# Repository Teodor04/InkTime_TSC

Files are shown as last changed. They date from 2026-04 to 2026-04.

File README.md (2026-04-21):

# InkTime Watch

A low-power e-paper smartwatch built around the **nRF52840**, designed for long battery life, sunlight readability, BLE connectivity, and essential wearable functionality such as notifications, timekeeping, basic motion tracking, and haptic feedback.

The platform integrates a **1.54" e-paper display**, **BLE 5.0**, **USB-C charging**, **battery fuel gauging**, **accelerometer-based activity tracking**, and a **haptic feedback driver**, all inside a compact custom enclosure.

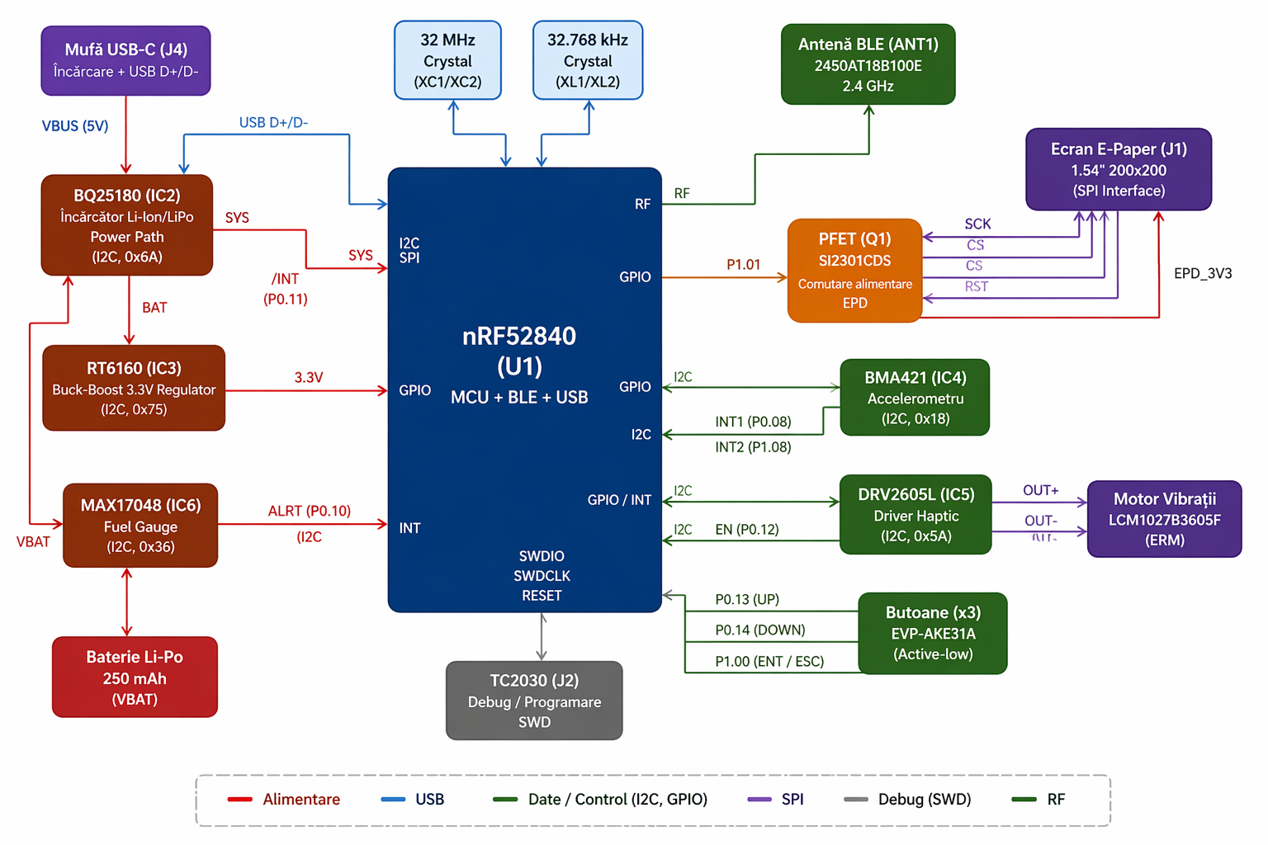
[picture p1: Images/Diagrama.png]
InkTime Watch Render


---

## Overview

InkTime Watch is a custom smartwatch hardware platform optimized for:
- **Ultra-low power consumption**
- **Always-readable e-paper display**
- **Bluetooth Low Energy communication**
- **Battery-powered operation**
- **Compact wearable form factor**

The system is centered on the **Nordic nRF52840**, which handles BLE communication, USB connectivity, GPIO control, and communication with all peripherals over SPI and I2C.

---

## Block Diagram

```text
                              ┌─────────────────────────────────────────────┐
                              │                 nRF52840                   │
                              │          MCU + BLE + USB Interface         │
                              │                                             │
                              │ SPI ───────────────► E-Paper Display        │
                              │ I2C ───────────────► BMA421                 │
                              │ I2C ───────────────► MAX17048               │
                              │ I2C ───────────────► BQ25180                │
                              │ I2C ───────────────► DRV2605L               │
                              │ GPIO ──────────────► Buttons                │
                              │ GPIO ──────────────► PFET Display Switch    │
                              │ SWDIO / SWDCLK ────► Tag-Connect SWD        │
                              │ D+ / D- ───────────► USB Type-C             │
                              │ ANT ───────────────► 2.4 GHz Antenna        │
                              │ XC1 / XC2 ─────────► 32 MHz Crystal         │
                              │ XL1 / XL2 ─────────► 32.768 kHz Crystal     │
                              └─────────────────────────────────────────────┘
                                              │
                                              ▼
                              ┌─────────────────────────────────────────────┐
                              │                 Power Tree                 │
                              │ USB 5V → BQ25180 → SYS → RT6160 → 3.3V    │
                              │ LiPo → BQ25180 BAT                         │
                              │ LiPo → MAX17048                            │
                              │ 3.3V → PFET → Switched EPD Rail           │
                              └─────────────────────────────────────────────┘

Bill of Materials (BOM)
Active & Critical Components
+----------------------+-------------------------------------------+-----------+------------+----------------------+
| Component            | Description                               | Package   | Part       | Datasheet            |
+----------------------+-------------------------------------------+-----------+------------+----------------------+
| nRF52840             | BLE 5.0 Cortex-M4F MCU                   | AQFN-73   | C190794    | Nordic nRF52840      |
| BQ25180YBGR          | 1A LiPo Charger (I2C)                    | DSBGA-8   | BQ25180YBGR| TI BQ25180           |
| MAX17048G+T10        | Fuel Gauge                              | TDFN-8    | C2682616   | Maxim MAX17048       |
| RT6160AWSC           | 3.3V Buck-Boost                         | WLCSP-15  | C7065276   | Richtek RT6160A      |
| BMA421               | IMU / Step Counter                      | LGA-12    | C5242966   | Bosch BMA421         |
| DRV2605YZFR          | Haptic Driver                           | DSBGA-9   | C527464    | TI DRV2605           |
| 2450AT18B100E        | 2.4GHz Antenna                          | 1206      | C2917717   | Johanson             |
| USBLC6-2SC6Y         | USB ESD Protection                      | SOT-23-6  | C2969755   | ST USBLC6-2          |
| KH-TYPE-C-16P        | USB-C Connector                         | SMD       | C168704    | Generic              |
| 503480-2400          | 24-pin FPC (EPD)                        | SMD       | —          | Molex                |
| DMG2305UX            | P-MOSFET (EPD power)                    | SOT-23    | C2940629   | Diodes Inc           |
| MBR0530              | Schottky Diode                          | SOD-123   | C77336     | Onsemi               |
| TC2030-IDC           | SWD Tag-Connect                         | PCB       | —          | Tag-Connect          |
+----------------------+-------------------------------------------+-----------+------------+----------------------+

Passive Components
+-----------------------------+-----------+--------+-----+-----------------------------+
| Component                   | Value     | Package| Qty | Function                    |
+-----------------------------+-----------+--------+-----+-----------------------------+
| Decoupling capacitors       | 100nF     | 0201   | 5   | MCU + peripherals           |
| Crystal load capacitors     | 12pF      | 0201   | 4   | Crystals                    |
| Bulk capacitors             | 4.7uF     | 0402   | 4   | Power buffering             |
| USB capacitor               | 4.7uF     | 0402   | 1   | USB stability               |
| Power capacitors            | 22uF      | 0402   | 2   | RT6160 input               |
| Charger capacitors          | 1uF       | 0402   | 3   | BQ25180 support            |
| E-paper capacitors          | 1uF / 50V | 0402   | 9   | Display driver             |
| MCU DC/DC inductor          | 10uH      | 0402   | 1   | nRF52840 regulator         |
| Buck-boost inductor         | 0.47uH    | 2012   | 1   | RT6160                     |
| I2C pull-up resistors       | 10k       | 0201   | 2   | SDA / SCL                  |
| USB-C CC resistors          | 5.1k      | 0201   | 2   | USB configuration          |
| Crystal                     | 32 MHz    | 2016   | 1   | MCU / RF clock             |
| Crystal                     | 32.768 kHz| 3215   | 1   | RTC                        |
+-----------------------------+-----------+--------+-----+-----------------------------+

## Hardware Description

### MCU - nRF52840

The **nRF52840** is the central processing unit of the InkTime watch. It integrates:

- **ARM Cortex-M4F** running at **64 MHz**, with floating-point unit
- **Bluetooth Low Energy 5.0**, used for time synchronization, notifications, and wireless communication
- **USB 2.0 Full Speed**, used for charging detection and firmware-related USB functionality
- **1 MB Flash** and **256 KB RAM**

The MCU coordinates all peripherals on the board. Communication with external devices is handled through:

- **SPI** for the e-paper display
- **I2C** for the motion sensor, fuel gauge, charger, regulator, and haptic driver

In addition to the communication buses, the MCU also manages:
- GPIO-based control lines for the display
- interrupt lines from peripherals
- button inputs
- haptic enable control
- SWD programming and debugging

---

### Power Architecture

The power system is designed around a rechargeable **single-cell Li-Po battery** and a **USB-C charging interface**.

```text
USB-C --> BQ25180 (charger / power path) --> Battery charging
                                     --> System rail

Battery --> MAX17048 --> battery monitoring
System rail / regulated rail --> MCU + peripherals
Display high-voltage rails --> generated by dedicated E-paper drive circuitry

BQ25180YBGR

The BQ25180 is the main charger and power-path management IC. It:

charges the Li-Po battery
monitors VBUS
provides system power management
generates interrupt/status events through PMIC_INT
communicates with the MCU over I2C
RT6160AWSC

The RT6160AWSC is used in the board power architecture as a switching regulator that helps generate the required regulated rail for the system.

MAX17048G+T10

The MAX17048 is a battery fuel gauge that monitors the battery voltage and estimates the state of charge (SOC) over I2C, allowing the firmware to display battery level and low-battery warnings.

E-Paper Display

The e-paper display is connected through an FPC connector and communicates with the MCU over SPI, together with several control GPIOs.

Signal	Direction	Description
SCK	MCU → EPD	SPI clock
MOSI	MCU → EPD	SPI data
EPD_CS	MCU → EPD	Chip select
EPD_DC	MCU → EPD	Data / Command select
EPD_RST	MCU → EPD	Hardware reset
EPD_BUSY	EPD → MCU	Busy flag

The display power rail is switched through a dedicated P-channel MOSFET, controlled by the MCU, so the panel can be powered only when needed. This reduces idle leakage and improves battery life.

The display driver circuitry generates the dedicated voltages required by the e-paper panel, such as:

PREVGH
PREVGL
VCOM
other gate/source driving rails required by the display
Motion Sensor - BMA421

The BMA421 is a low-power 3-axis accelerometer connected over I2C. It provides:

motion detection
step counting
orientation and activity-related sensing
interrupt-based wake-up functionality

Two interrupt lines are connected to the MCU:

IMU_INT1 for primary motion/step events
IMU_INT2 for additional event signaling or future extensions

This allows the MCU to remain in a low-power state and wake only when meaningful motion events occur.

Haptic Feedback - DRV2605 + ERM Motor

The DRV2605YZFR haptic driver controls the vibration motor used for user feedback. It connects to the MCU over I2C and also uses a dedicated digital enable signal:

HAPTIC_EN enables or disables the driver
OUT+ / OUT- drive the ERM motor
the chip supports waveform-based playback using its internal effects library

The haptic subsystem is used for:

notifications
alerts
button feedback
warning indications
USB Interface - KH-TYPE-C-16P + USBLC6-2SC6Y

The board uses a USB Type-C connector for charging and USB connectivity.

Main USB-related functions:

battery charging through VBUS
USB 2.0 D+ / D- lines connected to the nRF52840
ESD protection on USB data lines using USBLC6-2SC6Y
USB attach / power detection using the VBUS signal

The USB D+ / D- lines connect directly to the nRF52840 USB transceiver, while the USB-C configuration network ensures proper device operation.

RF Section - 2450AT18B100E Antenna

The board uses a 2.4 GHz chip antenna for BLE communication.

Key layout requirements for the RF section:

the antenna is placed at the PCB edge
copper is removed from the antenna keepout area
no signal traces are routed underneath the antenna
an impedance matching network is placed between the MCU RF pin and the antenna

This section is critical for BLE performance and must follow the recommended RF layout constraints.

SWD Debug - TC2030-IDC

Programming and debugging are performed through a Tag-Connect TC2030-IDC footprint.

The debug interface includes:

SWDIO
SWDCLK
nRESET
3.3V reference
GND

Additional exposed test pads are available for easier bring-up and debugging:

TP_SWDIO
TP_SWDCLK
TP_RESET
TP_3.3V
TP_GND

This allows programming and debugging without a permanently mounted header.

nRF52840 Pinout Specification
Shared I2C Bus

All I2C peripherals share the same bus, with pull-up resistors to 3.3V.

Pin	Function	Connected Devices
P0.06	SDA	BMA421, MAX17048, BQ25180, RT6160, DRV2605
P0.07	SCL	BMA421, MAX17048, BQ25180, RT6160, DRV2605
SPI Bus - E-Paper Display
Pin	Function	Description
P0.02	SCK	SPI clock for e-paper display
P0.03	MOSI	SPI data to e-paper display
P0.05	CS	E-paper chip select
P0.15	DC	Data / Command select
P0.16	RST	Display hardware reset
P0.17	BUSY	Display busy/status input
Display Power Control
Pin	Function	Description
P1.01	PFET Gate Control	Enables/disables the display power rail
Interrupts and Peripheral Control
Pin	Function	Description
P0.08	IMU_INT1	Primary motion / step wake interrupt
P1.08	IMU_INT2	Secondary motion interrupt
P0.10	ALRT	Fuel gauge alert / low battery interrupt
P0.11	PMIC_INT	Charger interrupt / status signal
P0.12	HAPTIC_EN	Enables the haptic driver
Physical Buttons

All buttons are connected as active-low inputs to GND.

Pin	Function
P0.13	Up Button
P0.14	Down Button
P1.00	Enter / Esc Button
Clocks and Debug
Pin / Signal	Function
XC1 / XC2	32 MHz crystal
XL1 / XL2	32.768 kHz crystal
SWDIO	SWD debug data
SWDCLK	SWD debug clock
nRESET	MCU reset
VBUS	USB power / attach detection
D+ / D-	Native USB 2.0
ANT	RF output to matching network and antenna
Pin Assignment Rationale

The pin assignment was chosen to keep routing compact and logically grouped:

I2C on P0.06 / P0.07 allows all low-speed peripherals to share a common bus.
SPI on P0.02 / P0.03 / P0.05 keeps display routing compact toward the FPC connector.
Display control pins are grouped close to the SPI bus to simplify routing.
Interrupt lines are placed on dedicated GPIOs so the MCU can identify wake sources immediately.
Buttons are assigned to GPIOs that can be routed toward the lower PCB edge, where the user interface is located.
HAPTIC_EN is placed near the I2C-related section for compact routing.
PFET gate control is placed on a dedicated GPIO to isolate display power switching from the communication buses.
SWDIO / SWDCLK / RESET are broken out to the Tag-Connect footprint for reliable programming and debug access.
Design Notes
The RF section must be kept clear of copper and routed carefully to preserve BLE performance.
The e-paper display requires dedicated high-voltage driving rails generated by the display power circuitry.
The charger, regulator, and battery monitoring ICs form the core of the power subsystem.
The design uses both communication buses and dedicated GPIO control to balance flexibility, low power, and routing simplicity.

License

This project is intended for educational use unless otherwise specified.

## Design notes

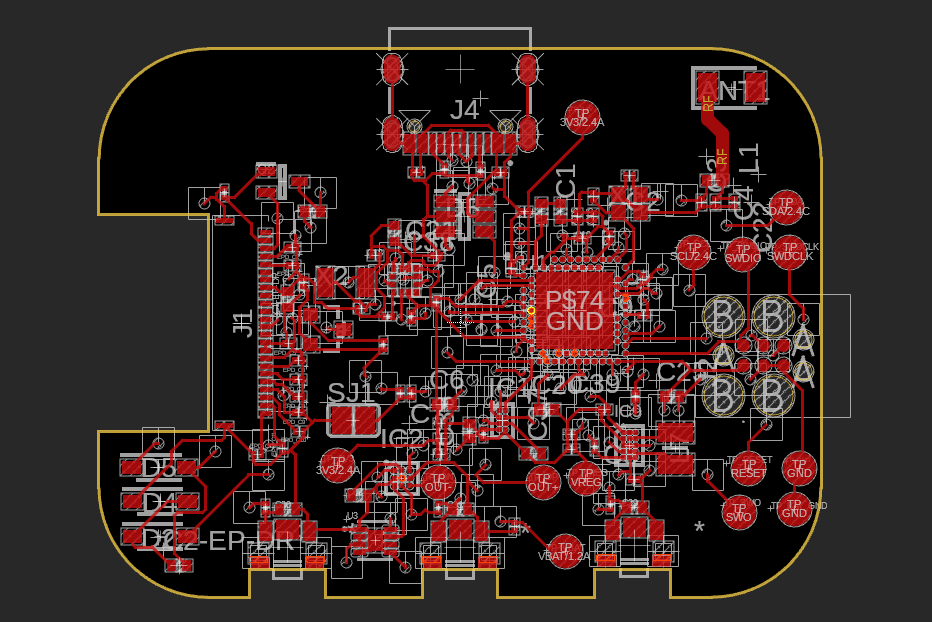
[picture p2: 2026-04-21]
Images/pcb2dtop.png

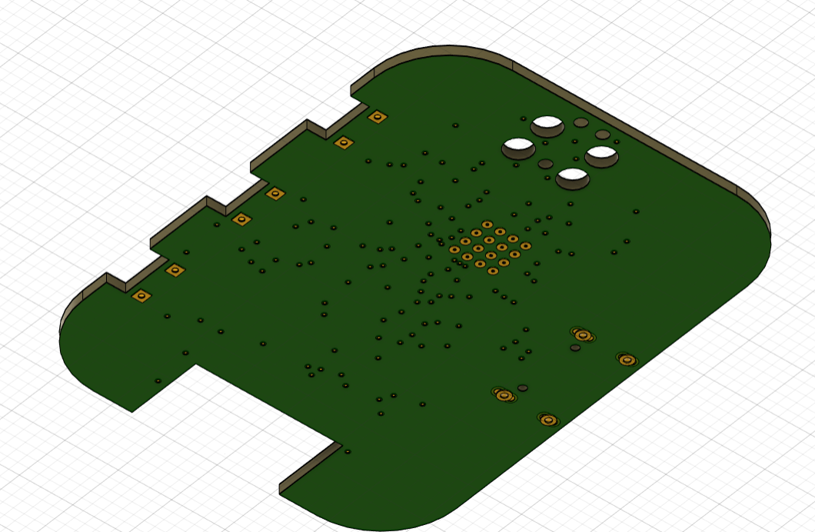
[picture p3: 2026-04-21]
Images/pcb 3d bottom.png

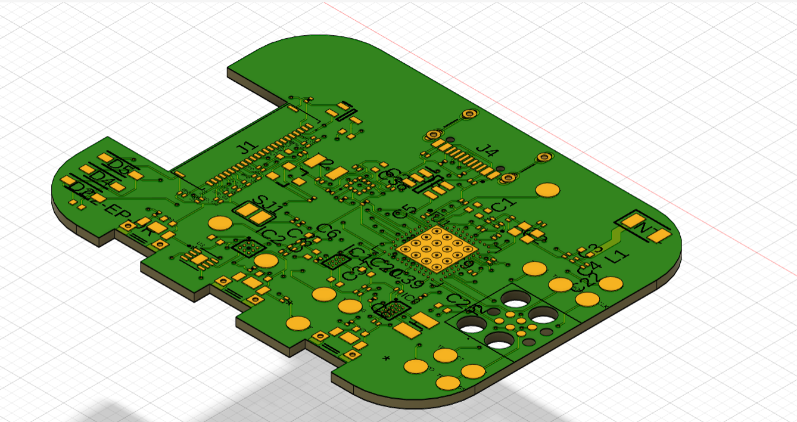
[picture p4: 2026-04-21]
Images/pcb 3d top.png

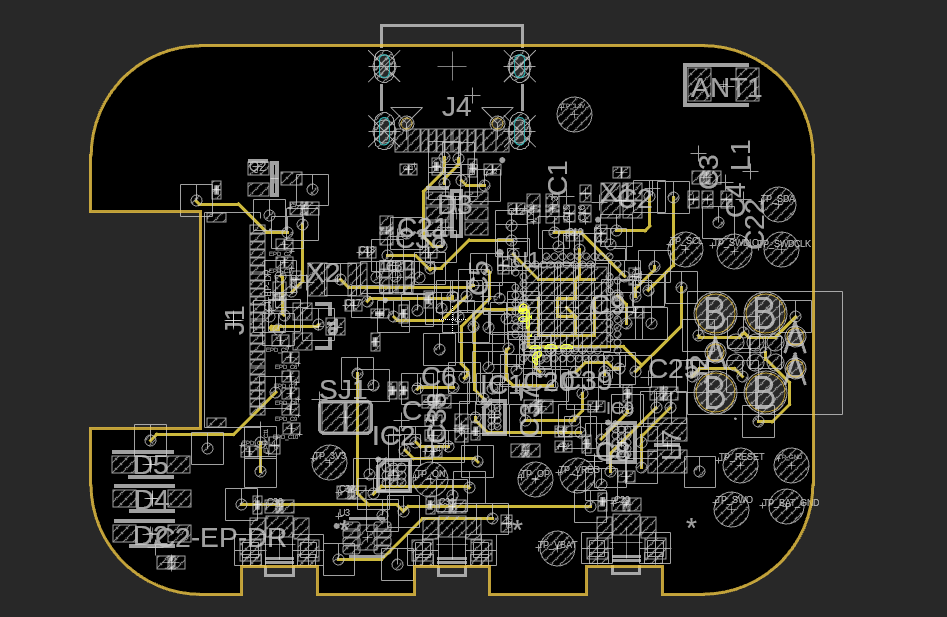
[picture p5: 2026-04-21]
Images/pcb2dgnd.png

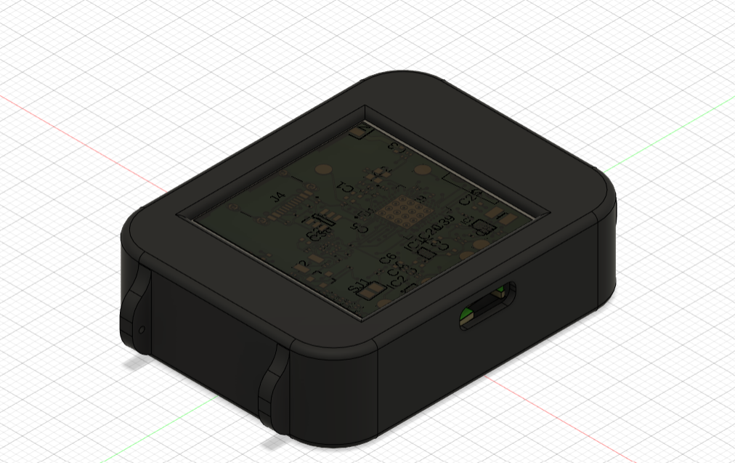
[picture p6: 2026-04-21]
Images/watch.png

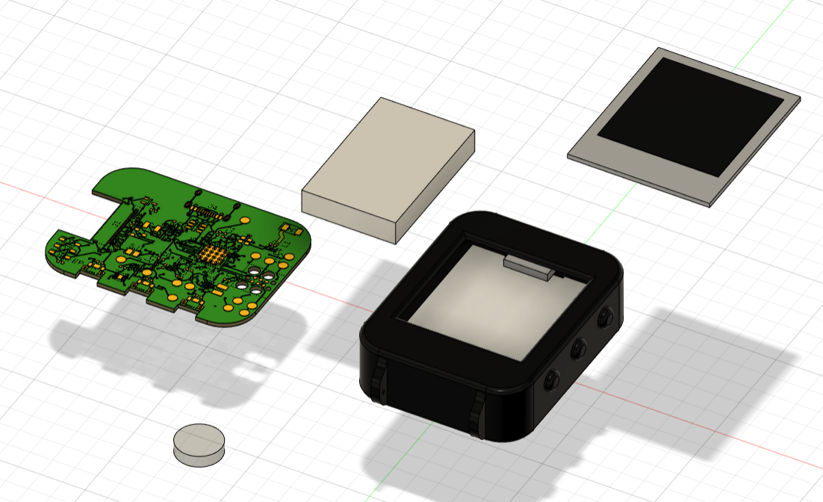
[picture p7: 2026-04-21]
Images/exploded.png

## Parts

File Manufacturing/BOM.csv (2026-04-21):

Part | Value | Device | Footprint Name | Detailed Description | ARROW_PART_NUMBER | ARROW_PRICE-STOCK | AVAILABILITY | CHECK_PRICES | COPYRIGHT | DESCRIPTION | DIGI-KEY_PART_NUMBER_1 | DIGI-KEY_PART_NUMBER_2 | DIGI-KEY_PART_NUMBER_3 | HEIGHT | JLCPCB | MANUFACTURER_NAME | MANUFACTURER_PART_NUMBER | MF | MOUSER_PART_NUMBER | MOUSER_PRICE-STOCK | MP | PACKAGE | POPULARITY | PRICE | PROD_ID | PURCHASE-URL | SNAPEDA_LINK | TP_SIGNAL_NAME | VALUE
ANT1 | 2450AT18B100E_2450AT18B100E | 2450AT18B100E_2450AT18B100E | 2450AT18B100E_ANTC3216X140N | Antennas 2.45GHz ANTENNA | 2450AT18B100E | https://www.arrow.com/en/products/2450at18b100e/johanson-dielectrics?utm_currency=USD&region=nac |  |  |  | Antennas 2.45GHz ANTENNA |  |  |  | 1.4mm |  | JOHANSON TECHNOLOGY | 2450AT18B100E |  | 609-2450AT18B100E | https://www.mouser.co.uk/ProductDetail/Johanson-Technology/2450AT18B100E?qs=yCnrNFeXz%252Bh5MFsFIXGZGA%3D%3D
C1 | 12pF | NORDIC_NRF_3_CAPACITOR_0201_L | NORDIC_NRF_3_RESC0201_L | Generic chip capacitor
C1-EP-DR | 10uF | NORDIC_NRF_3_CAPACITOR_0402_L | NORDIC_NRF_3_RESC0402_L | Generic chip capacitor
C2 | 12pF | NORDIC_NRF_3_CAPACITOR_0201_L | NORDIC_NRF_3_RESC0201_L | Generic chip capacitor
C2-EP-DR | 4.7uF/25V | NORDIC_NRF_3_CAPACITOR_0402_L | NORDIC_NRF_3_RESC0402_L | Generic chip capacitor
C3 | 1pF | NORDIC_NRF_3_CAPACITOR_0201_L | NORDIC_NRF_3_RESC0201_L | Generic chip capacitor
C4 | 1pF | NORDIC_NRF_3_CAPACITOR_0201_L | NORDIC_NRF_3_RESC0201_L | Generic chip capacitor
C5 | 100nF | NORDIC_NRF_3_CAPACITOR_0201_L | NORDIC_NRF_3_RESC0201_L | Generic chip capacitor
C6 | 4.7µF | NORDIC_NRF_3_CAPACITOR_0402_L | NORDIC_NRF_3_RESC0402_L | Generic chip capacitor
C7 | 100nF | NORDIC_NRF_3_CAPACITOR_0201_L | NORDIC_NRF_3_RESC0201_L | Generic chip capacitor
C8 | 100nF | NORDIC_NRF_3_CAPACITOR_0201_L | NORDIC_NRF_3_RESC0201_L | Generic chip capacitor
C9 | 820pF | NORDIC_NRF_3_CAPACITOR_0201_L | NORDIC_NRF_3_RESC0201_L | Generic chip capacitor
C10 | N.C. | NORDIC_NRF_3_CAPACITOR_0201_L | NORDIC_NRF_3_RESC0201_L | Generic chip capacitor
C11 | 100pF | NORDIC_NRF_3_CAPACITOR_0201_L | NORDIC_NRF_3_RESC0201_L | Generic chip capacitor
C12 | 100nF | NORDIC_NRF_3_CAPACITOR_0201_L | NORDIC_NRF_3_RESC0201_L | Generic chip capacitor
C13 | N.C. | NORDIC_NRF_3_CAPACITOR_0201_L | NORDIC_NRF_3_RESC0201_L | Generic chip capacitor
C14 | 4.7µF | NORDIC_NRF_3_CAPACITOR_0201_L | NORDIC_NRF_3_RESC0201_L | Generic chip capacitor
C15 | 1.0µF | NORDIC_NRF_3_CAPACITOR_0201_L | NORDIC_NRF_3_RESC0201_L | Generic chip capacitor
C16 | 47nF | NORDIC_NRF_3_CAPACITOR_0201_L | NORDIC_NRF_3_RESC0201_L | Generic chip capacitor
C17 | 12pF | NORDIC_NRF_3_CAPACITOR_0201_L | NORDIC_NRF_3_RESC0201_L | Generic chip capacitor
C18 | 12pF | NORDIC_NRF_3_CAPACITOR_0201_L | NORDIC_NRF_3_RESC0201_L | Generic chip capacitor
C19 | 100nF | NORDIC_NRF_3_CAPACITOR_0201_L | NORDIC_NRF_3_RESC0201_L | Generic chip capacitor
C20 | 4.7µF | NORDIC_NRF_3_CAPACITOR_0402_L | NORDIC_NRF_3_RESC0402_L | Generic chip capacitor
C21 | 4.7µF | NORDIC_NRF_3_CAPACITOR_0201_L | NORDIC_NRF_3_RESC0201_L | Generic chip capacitor
C22 | N.C. | NORDIC_NRF_3_CAPACITOR_0201_L | NORDIC_NRF_3_RESC0201_L | Generic chip capacitor
C23 | 0.1uF | NORDIC_NRF_3_CAPACITOR_0201_L | NORDIC_NRF_3_RESC0201_L | Generic chip capacitor
C24 | 10uF | NORDIC_NRF_3_CAPACITOR_0201_L | NORDIC_NRF_3_RESC0201_L | Generic chip capacitor
C25 | 22uF | NORDIC_NRF_3_CAPACITOR_0402_L | NORDIC_NRF_3_RESC0402_L | Generic chip capacitor
C27 | 0.1uF | NORDIC_NRF_3_CAPACITOR_0201_L | NORDIC_NRF_3_RESC0201_L | Generic chip capacitor
C29 | 1uF | NORDIC_NRF_3_CAPACITOR_0402_L | NORDIC_NRF_3_RESC0402_L | Generic chip capacitor
C30 | 1uF | NORDIC_NRF_3_CAPACITOR_0402_L | NORDIC_NRF_3_RESC0402_L | Generic chip capacitor
C31 | 1uF | NORDIC_NRF_3_CAPACITOR_0402_L | NORDIC_NRF_3_RESC0402_L | Generic chip capacitor
C32 | 1uF | NORDIC_NRF_3_CAPACITOR_0402_L | NORDIC_NRF_3_RESC0402_L | Generic chip capacitor
C33 | 22uF | NORDIC_NRF_3_CAPACITOR_0402_L | NORDIC_NRF_3_RESC0402_L | Generic chip capacitor
C34 | 0.1uF | NORDIC_NRF_3_CAPACITOR_0201_L | NORDIC_NRF_3_RESC0201_L | Generic chip capacitor
C37 | 1uF | NORDIC_NRF_3_CAPACITOR_0402_L | NORDIC_NRF_3_RESC0402_L | Generic chip capacitor
C38 | 1uF | NORDIC_NRF_3_CAPACITOR_0402_L | NORDIC_NRF_3_RESC0402_L | Generic chip capacitor
C39 | 10uF | NORDIC_NRF_3_CAPACITOR_0201_L | NORDIC_NRF_3_RESC0201_L | Generic chip capacitor
C42 | 0.1uF | NORDIC_NRF_3_CAPACITOR_0201_L | NORDIC_NRF_3_RESC0201_L | Generic chip capacitor
C43 | 4.7uF | NORDIC_NRF_3_CAPACITOR_0201_L | NORDIC_NRF_3_RESC0201_L | Generic chip capacitor
D2 | ESP32_C6_LIBRARY_5_MBR0530 | ESP32_C6_LIBRARY_5_MBR0530 | ESP32_C6_LIBRARY_5_SOD3716X135N | ON SEMICONDUCTOR - MBR0530 - DIODE, SCHOTTKY, 0.5A, 30V, SOD-123 |  |  | In Stock | https://www.snapeda.com/parts/MBR0530/Onsemi/view-part/?ref=eda |  | Diode Schottky 30 V 500mA Surface Mount SOD-123 |  |  |  |  |  |  |  | ON Semiconductor |  |  | MBR0530 | SOD-123-2 ON Semiconductor |  | None |  | https://www.snapeda.com/api/url_track_click_mouser/?unipart_id=179458&manufacturer=ON Semiconductor&part_name=MBR0530&search_term=None | https://www.snapeda.com/parts/MBR0530/Onsemi/view-part/?ref=snap
D3 | ESP32_C6_LIBRARY_3_USBLC6-2SC6Y | ESP32_C6_LIBRARY_3_USBLC6-2SC6Y | ESP32_C6_LIBRARY_3_SOT95P280X145-6N | Low Cap. ESD Protection Auto SOT-23-6 STMicroelectronics USBLC6-2SC6Y, Dual Uni-Directional TVS Diode Array, 6-Pin SOT-23 |  |  | In Stock | https://www.snapeda.com/parts/USBLC6-2SC6Y/STMicroelectronics/view-part/?ref=eda |  | 17V Clamp 5A (8/20µs) Ipp Tvs Diode Surface Mount SOT-23-6 |  |  |  |  |  |  |  | STMicroelectronics |  |  | USBLC6-2SC6Y | SOT-23-6 STMicroelectronics |  | None |  |  | https://www.snapeda.com/parts/USBLC6-2SC6Y/STMicroelectronics/view-part/?ref=snap
D4 | ESP32_C6_LIBRARY_5_MBR0530 | ESP32_C6_LIBRARY_5_MBR0530 | ESP32_C6_LIBRARY_5_SOD3716X135N | ON SEMICONDUCTOR - MBR0530 - DIODE, SCHOTTKY, 0.5A, 30V, SOD-123 |  |  | In Stock | https://www.snapeda.com/parts/MBR0530/Onsemi/view-part/?ref=eda |  | Diode Schottky 30 V 500mA Surface Mount SOD-123 |  |  |  |  |  |  |  | ON Semiconductor |  |  | MBR0530 | SOD-123-2 ON Semiconductor |  | None |  | https://www.snapeda.com/api/url_track_click_mouser/?unipart_id=179458&manufacturer=ON Semiconductor&part_name=MBR0530&search_term=None | https://www.snapeda.com/parts/MBR0530/Onsemi/view-part/?ref=snap
D5 | ESP32_C6_LIBRARY_5_MBR0530 | ESP32_C6_LIBRARY_5_MBR0530 | ESP32_C6_LIBRARY_5_SOD3716X135N | ON SEMICONDUCTOR - MBR0530 - DIODE, SCHOTTKY, 0.5A, 30V, SOD-123 |  |  | In Stock | https://www.snapeda.com/parts/MBR0530/Onsemi/view-part/?ref=eda |  | Diode Schottky 30 V 500mA Surface Mount SOD-123 |  |  |  |  |  |  |  | ON Semiconductor |  |  | MBR0530 | SOD-123-2 ON Semiconductor |  | None |  | https://www.snapeda.com/api/url_track_click_mouser/?unipart_id=179458&manufacturer=ON Semiconductor&part_name=MBR0530&search_term=None | https://www.snapeda.com/parts/MBR0530/Onsemi/view-part/?ref=snap
EPD_C1 | 1uF/50V | NORDIC_NRF_3_CAPACITOR_0201_L | NORDIC_NRF_3_RESC0201_L | Generic chip capacitor
EPD_C2 | 1uF/50V | NORDIC_NRF_3_CAPACITOR_0201_L | NORDIC_NRF_3_RESC0201_L | Generic chip capacitor
EPD_C5 | 0.1uF/50V | NORDIC_NRF_3_CAPACITOR_0201_L | NORDIC_NRF_3_RESC0201_L | Generic chip capacitor
EPD_C6 | 1uF/50V | NORDIC_NRF_3_CAPACITOR_0201_L | NORDIC_NRF_3_RESC0201_L | Generic chip capacitor
EPD_C7 | 1uF/50V | NORDIC_NRF_3_CAPACITOR_0201_L | NORDIC_NRF_3_RESC0201_L | Generic chip capacitor
EPD_C8 | 1uF/50V | NORDIC_NRF_3_CAPACITOR_0201_L | NORDIC_NRF_3_RESC0201_L | Generic chip capacitor
EPD_C9 | 1uF/50V | NORDIC_NRF_3_CAPACITOR_0201_L | NORDIC_NRF_3_RESC0201_L | Generic chip capacitor
EPD_C10 | 1uF/50V | NORDIC_NRF_3_CAPACITOR_0201_L | NORDIC_NRF_3_RESC0201_L | Generic chip capacitor
EPD_C11 | 1uF/50V | NORDIC_NRF_3_CAPACITOR_0201_L | NORDIC_NRF_3_RESC0201_L | Generic chip capacitor
EPD_C12 | 1uF/50V | NORDIC_NRF_3_CAPACITOR_0201_L | NORDIC_NRF_3_RESC0201_L | Generic chip capacitor
IC1 | BQ25180YBGR_BQ25180YBGR | BQ25180YBGR_BQ25180YBGR | BQ25180YBGR_BGA8C40P2X4_100X155X50 | Charger IC Lithium Ion/Polymer, Lithium Iron Phosphate 8-DSBGA (1.6x1.1) | BQ25180YBGR | https://www.arrow.com/en/products/bq25180ybgr/texas-instruments?utm_currency=USD&region=nac |  |  |  | Charger IC Lithium Ion/Polymer, Lithium Iron Phosphate 8-DSBGA (1.6x1.1) |  |  |  | 0.5mm |  | Texas Instruments | BQ25180YBGR |  | 595-BQ25180YBGR | https://www.mouser.co.uk/ProductDetail/Texas-Instruments/BQ25180YBGR?qs=doiCPypUmgEWjAK%252BJAX6Tw%3D%3D
IC2 | DRV2605YZFR_DRV2605YZFR | DRV2605YZFR_DRV2605YZFR | DRV2605YZFR_BGA9C50P3X3_144X144X62 | Haptic Driver for ERM/LRA with Built-In Library and Smart Loop Architecture | DRV2605YZFR | https://www.arrow.com/en/products/drv2605yzfr/texas-instruments?region=nac |  |  |  | Haptic Driver for ERM/LRA with Built-In Library and Smart Loop Architecture |  |  |  | 0.625mm |  | Texas Instruments | DRV2605YZFR
IC3 | BMA423_BMA423 | BMA423_BMA423 | BMA423_BMA423 | Accelerometers Triaxial low-g 12bit Acceleration Sensor | BMA423 | https://www.arrow.com/en/products/bma423/bosch |  |  |  | Accelerometers Triaxial low-g 12bit Acceleration Sensor |  |  |  | 1mm |  | BOSCH | BMA423 |  | 262-BMA423 | https://www.mouser.co.uk/ProductDetail/Bosch-Sensortec/BMA423?qs=HXFqYaX1Q2xC%252BSgeGoX3mg%3D%3D
IC9 | RT6160AWSC_RT6160AWSC | RT6160AWSC_RT6160AWSC | RT6160AWSC_BGA15C40P3X5_140X230X60 | Buck-Boost Regulator Positive Output Step-Up/Step-Down I2C DC-DC Controller IC 15-WL-CSP (BSC) (1.4x2.3) |  |  |  |  |  | Buck-Boost Regulator Positive Output Step-Up/Step-Down I2C DC-DC Controller IC 15-WL-CSP (BSC) (1.4x2.3) |  |  |  | 0.6mm |  | RICHTEK | RT6160AWSC |  | 835-RT6160AWSC | https://www.mouser.co.uk/ProductDetail/Richtek/RT6160AWSC?qs=amGC7iS6iy%2FLd9PSoixZXQ%3D%3D
J1 | 503480-2400_503480-2400 | 503480-2400_503480-2400 | 503480-2400_5034802400 | FFC & FPC Connectors 0.5mm FPC RA SMT Dual Contact 24Ckt |  |  |  |  |  | FFC & FPC Connectors 0.5mm FPC RA SMT Dual Contact 24Ckt |  |  |  | 1.87mm |  | Molex | 503480-2400 |  | 538-503480-2400 | https://www.mouser.co.uk/ProductDetail/Molex/503480-2400?qs=OAhjpuo3Vu7efIoxFh9AOw%3D%3D
J2 | TC2030-IDC_TC2030-IDC | TC2030-IDC_TC2030-IDC | TC2030-IDC_TC2030IDC | CABLE ADAPTER 6 POS |  |  |  |  |  | CABLE ADAPTER 6 POS |  |  |  | 19mm |  | Tag Connect | TC2030-IDC
J4 | KH-TYPE-C-16P_KH-TYPE-C-16P | KH-TYPE-C-16P_KH-TYPE-C-16P | KH-TYPE-C-16P_KINGHELM_KH-TYPE-C-16P | Check availability |  |  | Not in stock | https://www.snapeda.com/parts/KH-TYPE-C-16P/Kinghelm/view-part/?ref=eda |  |  |  |  |  |  |  |  |  | kinghelm |  |  | KH-TYPE-C-16P | None |  | None |  |  | https://www.snapeda.com/parts/KH-TYPE-C-16P/Kinghelm/view-part/?ref=snap
L1 | 3.9nH | NORDIC_NRF_2_INDUCTOR_0402_L | NORDIC_NRF_2_RESC0402_L | Generic chip inductor
L2 | 10µH | NORDIC_NRF_2_INDUCTOR_0402_L | NORDIC_NRF_2_RESC0402_L | Generic chip inductor
L3 | 15nH | NORDIC_NRF_2_INDUCTOR_0402_L | NORDIC_NRF_2_RESC0402_L | Generic chip inductor
L5 | 68uH | NORDIC_NRF_2_INDUCTOR_0402_L | NORDIC_NRF_2_RESC0402_L | Generic chip inductor
L7 | MLP2016SR47MT0S1_FTC252012SR47MBCA | MLP2016SR47MT0S1_FTC252012SR47MBCA | MLP2016SR47MT0S1_INDC2016X100N | SMD / SMT Inductors (Coils), L=0.47?H, L x W x T : |  |  |  |  |  | SMD / SMT Inductors (Coils), L=0.47?H, L x W x T : |  |  |  | 1mm | https://jlcpcb.com/partdetail/6763488-FTC252012SR47MBCA/C5832368 | TDK | FTC252012SR47MBCA
Q1 | 20V/4.2A/52mO/1.4W | ESP32_C6_LIBRARY_4_ESP32_WROVER_SPARKFUN-DISCRETESEMI_MOSFET_PCH-DMG2305UX-7 | ESP32_C6_LIBRARY_4_ESP32_C6_LIBRARY_4_ESP32_C6_LIBRARY_4_ESP32_C6_LIBRARY_4_ESP32_WROVER_SPARKFUN-DISCRETESEMI_SOT23-3 | P-channel MOSFETs |  |  |  |  |  |  |  |  |  |  |  |  |  |  |  |  |  |  |  |  | TRAN-14388 |  |  |  | 20V/4.2A/52mO/1.4W
Q2 | ESP32_C6_LIBRARY_6_SI1308EDL-T1-GE3 | ESP32_C6_LIBRARY_6_SI1308EDL-T1-GE3 | ESP32_C6_LIBRARY_6_SOT65P210X110-3N | MOSFET N-Ch 30V 1.5A TrenchFET SC70 Vishay Si1308EDL-T1-GE3 N-channel MOSFET Transistor, 1.5 A, 30 V, 3-Pin SC-70 |  |  | In Stock | https://www.snapeda.com/parts/SI1308EDL-T1-GE3/Vishay+Siliconix/view-part/?ref=eda |  | Si1308EDL-T1-GE3 N-channel MOSFET Transistor, 1.5 A, 30 V, 3-Pin SC-70 | Siliconix / Vishay SI1308EDL-T1-GE3 |  |  |  |  |  |  |  | Vishay Siliconix |  |  | SI1308EDL-T1-GE3 | SOT-323 Vishay Semiconductor |  | None |  | https://www.snapeda.com/api/url_track_click_mouser/?unipart_id=274603&manufacturer=Vishay Siliconix&part_name=SI1308EDL-T1-GE3&search_term=None | https://www.snapeda.com/parts/SI1308EDL-T1-GE3/Vishay+Siliconix/view-part/?ref=snap
R1_EP_DR | 0.47 | CPF0201D7K68C1_CPF0201D7K68C1 | CPF0201D7K68C1_0201 | 7.68k 0201 Thin Film Surface Mount Fixed Resistor +/-0.5% 0.031W CPF0201D7K68C1
R1_USB | 5K1 | CPF0201D7K68C1_CPF0201D7K68C1 | CPF0201D7K68C1_0201 | 7.68k 0201 Thin Film Surface Mount Fixed Resistor +/-0.5% 0.031W CPF0201D7K68C1
R2 | 0 | CPF0201D7K68C1_CPF0201D7K68C1 | CPF0201D7K68C1_0201 | 7.68k 0201 Thin Film Surface Mount Fixed Resistor +/-0.5% 0.031W CPF0201D7K68C1
R2_EP_DR | 10K | CPF0201D7K68C1_CPF0201D7K68C1 | CPF0201D7K68C1_0201 | 7.68k 0201 Thin Film Surface Mount Fixed Resistor +/-0.5% 0.031W CPF0201D7K68C1
R2_USB | 5K1 | CPF0201D7K68C1_CPF0201D7K68C1 | CPF0201D7K68C1_0201 | 7.68k 0201 Thin Film Surface Mount Fixed Resistor +/-0.5% 0.031W CPF0201D7K68C1
R3 | 0 | CPF0201D7K68C1_CPF0201D7K68C1 | CPF0201D7K68C1_0201 | 7.68k 0201 Thin Film Surface Mount Fixed Resistor +/-0.5% 0.031W CPF0201D7K68C1
R4 | 0 | CPF0201D7K68C1_CPF0201D7K68C1 | CPF0201D7K68C1_0201 | 7.68k 0201 Thin Film Surface Mount Fixed Resistor +/-0.5% 0.031W CPF0201D7K68C1
R5 | 10k | CPF0201D7K68C1_CPF0201D7K68C1 | CPF0201D7K68C1_0201 | 7.68k 0201 Thin Film Surface Mount Fixed Resistor +/-0.5% 0.031W CPF0201D7K68C1
R7 | 10k | CPF0201D7K68C1_CPF0201D7K68C1 | CPF0201D7K68C1_0201 | 7.68k 0201 Thin Film Surface Mount Fixed Resistor +/-0.5% 0.031W CPF0201D7K68C1
R8 | 10k | CPF0201D7K68C1_CPF0201D7K68C1 | CPF0201D7K68C1_0201 | 7.68k 0201 Thin Film Surface Mount Fixed Resistor +/-0.5% 0.031W CPF0201D7K68C1
R9 | 10K | CPF0201D7K68C1_CPF0201D7K68C1 | CPF0201D7K68C1_0201 | 7.68k 0201 Thin Film Surface Mount Fixed Resistor +/-0.5% 0.031W CPF0201D7K68C1
R17 | 3K3 | CPF0201D7K68C1_CPF0201D7K68C1 | CPF0201D7K68C1_0201 | 7.68k 0201 Thin Film Surface Mount Fixed Resistor +/-0.5% 0.031W CPF0201D7K68C1
R18 | 3K3 | CPF0201D7K68C1_CPF0201D7K68C1 | CPF0201D7K68C1_0201 | 7.68k 0201 Thin Film Surface Mount Fixed Resistor +/-0.5% 0.031W CPF0201D7K68C1
R_PWR_EPD | 10K | CPF0201D7K68C1_CPF0201D7K68C1 | CPF0201D7K68C1_0201 | 7.68k 0201 Thin Film Surface Mount Fixed Resistor +/-0.5% 0.031W CPF0201D7K68C1
R_TYPE_SEL | 2.2 | CPF0201D7K68C1_CPF0201D7K68C1 | CPF0201D7K68C1_0201 | 7.68k 0201 Thin Film Surface Mount Fixed Resistor +/-0.5% 0.031W CPF0201D7K68C1
SJ1 |  | ESP32_C6_LIBRARY_7_JUMPER_SJ | ESP32_C6_LIBRARY_7_JUMPER_SJ | SMD solder JUMPER |  |  |  |  |  |  |  |  |  |  |  |  |  |  |  |  |  |  | 3
SW_DN | 2025-10-22_07-23-44_LIBRARY_EVP-AKE31ASW_EVP-AKE31A_PAN | 2025-10-22_07-23-44_LIBRARY_EVP-AKE31ASW_EVP-AKE31A_PAN | 2025-10-22_07-23-44_LIBRARY_SW_EVP-AKE31A_PAN |  |  |  |  |  | Copyright (C) 2025 Ultra Librarian. All rights reserved. |  | P123437TR-ND | P123437CT-ND | P123437DKR-ND |  |  | Panasonic | EVP-AKE31A
SW_ENT | 2025-10-22_07-23-44_LIBRARY_EVP-AKE31ASW_EVP-AKE31A_PAN | 2025-10-22_07-23-44_LIBRARY_EVP-AKE31ASW_EVP-AKE31A_PAN | 2025-10-22_07-23-44_LIBRARY_SW_EVP-AKE31A_PAN |  |  |  |  |  | Copyright (C) 2025 Ultra Librarian. All rights reserved. |  | P123437TR-ND | P123437CT-ND | P123437DKR-ND |  |  | Panasonic | EVP-AKE31A
SW_UP | 2025-10-22_07-23-44_LIBRARY_EVP-AKE31ASW_EVP-AKE31A_PAN | 2025-10-22_07-23-44_LIBRARY_EVP-AKE31ASW_EVP-AKE31A_PAN | 2025-10-22_07-23-44_LIBRARY_SW_EVP-AKE31A_PAN |  |  |  |  |  | Copyright (C) 2025 Ultra Librarian. All rights reserved. |  | P123437TR-ND | P123437CT-ND | P123437DKR-ND |  |  | Panasonic | EVP-AKE31A
TP_3.3V | HECTOR_WATCH_1_TPTP20R | HECTOR_WATCH_1_TPTP20R | HECTOR_WATCH_1_TP20R | Test pad |  |  |  |  |  |  |  |  |  |  |  |  |  |  |  |  |  |  | 2
TP_3V3 | HECTOR_WATCH_1_TPTP20R | HECTOR_WATCH_1_TPTP20R | HECTOR_WATCH_1_TP20R | Test pad |  |  |  |  |  |  |  |  |  |  |  |  |  |  |  |  |  |  | 2
TP_BAT_GND | HECTOR_WATCH_1_TPTP20R | HECTOR_WATCH_1_TPTP20R | HECTOR_WATCH_1_TP20R | Test pad |  |  |  |  |  |  |  |  |  |  |  |  |  |  |  |  |  |  | 2
TP_GND | HECTOR_WATCH_1_TPTP20R | HECTOR_WATCH_1_TPTP20R | HECTOR_WATCH_1_TP20R | Test pad |  |  |  |  |  |  |  |  |  |  |  |  |  |  |  |  |  |  | 2
TP_ON | HECTOR_WATCH_1_TPTP20R | HECTOR_WATCH_1_TPTP20R | HECTOR_WATCH_1_TP20R | Test pad |  |  |  |  |  |  |  |  |  |  |  |  |  |  |  |  |  |  | 2
TP_OP | HECTOR_WATCH_1_TPTP20R | HECTOR_WATCH_1_TPTP20R | HECTOR_WATCH_1_TP20R | Test pad |  |  |  |  |  |  |  |  |  |  |  |  |  |  |  |  |  |  | 2
TP_RESET | HECTOR_WATCH_1_TPTP20R | HECTOR_WATCH_1_TPTP20R | HECTOR_WATCH_1_TP20R | Test pad |  |  |  |  |  |  |  |  |  |  |  |  |  |  |  |  |  |  | 2
TP_SCL | HECTOR_WATCH_1_TPTP20R | HECTOR_WATCH_1_TPTP20R | HECTOR_WATCH_1_TP20R | Test pad |  |  |  |  |  |  |  |  |  |  |  |  |  |  |  |  |  |  | 2
TP_SDA | HECTOR_WATCH_1_TPTP20R | HECTOR_WATCH_1_TPTP20R | HECTOR_WATCH_1_TP20R | Test pad |  |  |  |  |  |  |  |  |  |  |  |  |  |  |  |  |  |  | 2
TP_SWDCLK | HECTOR_WATCH_1_TPTP20R | HECTOR_WATCH_1_TPTP20R | HECTOR_WATCH_1_TP20R | Test pad |  |  |  |  |  |  |  |  |  |  |  |  |  |  |  |  |  |  | 2
TP_SWDIO | HECTOR_WATCH_1_TPTP20R | HECTOR_WATCH_1_TPTP20R | HECTOR_WATCH_1_TP20R | Test pad |  |  |  |  |  |  |  |  |  |  |  |  |  |  |  |  |  |  | 2
TP_SWO | HECTOR_WATCH_1_TPTP20R | HECTOR_WATCH_1_TPTP20R | HECTOR_WATCH_1_TP20R | Test pad |  |  |  |  |  |  |  |  |  |  |  |  |  |  |  |  |  |  | 2
TP_VBAT | HECTOR_WATCH_1_TPTP20R | HECTOR_WATCH_1_TPTP20R | HECTOR_WATCH_1_TP20R | Test pad |  |  |  |  |  |  |  |  |  |  |  |  |  |  |  |  |  |  | 2
TP_VREG | HECTOR_WATCH_1_TPTP20R | HECTOR_WATCH_1_TPTP20R | HECTOR_WATCH_1_TP20R | Test pad |  |  |  |  |  |  |  |  |  |  |  |  |  |  |  |  |  |  | 2
U1 | NORDIC_NRF_4_NRF52840_QF | NORDIC_NRF_4_NRF52840_QF | NORDIC_NRF_4_AQFN50P700X700X85_HS-74N | nRF52840
U3 | ESP32_C6_LIBRARY_MAX17048G+T10 | ESP32_C6_LIBRARY_MAX17048G+T10 | ESP32_C6_LIBRARY_SON50P200X200X80-9N | Check availability |  |  | In Stock | https://www.snapeda.com/parts/MAX17048G+T10/Analog+Devices/view-part/?ref=eda |  | 3µA 1-Cell/2-Cell Fuel Gauge with ModelGauge |  |  |  |  |  |  |  | Analog Devices |  |  | MAX17048G+T10 | TDFN-8 Maxim |  | None |  | https://www.snapeda.com/api/url_track_click_mouser/?unipart_id=329239&manufacturer=Analog Devices&part_name=MAX17048G+T10&search_term=None | https://www.snapeda.com/parts/MAX17048G+T10/Analog+Devices/view-part/?ref=snap
X1 | 32MHz | NORDIC_NRF_XTAL_32MHZ | NORDIC_NRF_BT-XTAL_2016_N
X2 | 32.768kHz | NORDIC_NRF_1_XTAL_32KHZ | NORDIC_NRF_1_XTAL_3215_N

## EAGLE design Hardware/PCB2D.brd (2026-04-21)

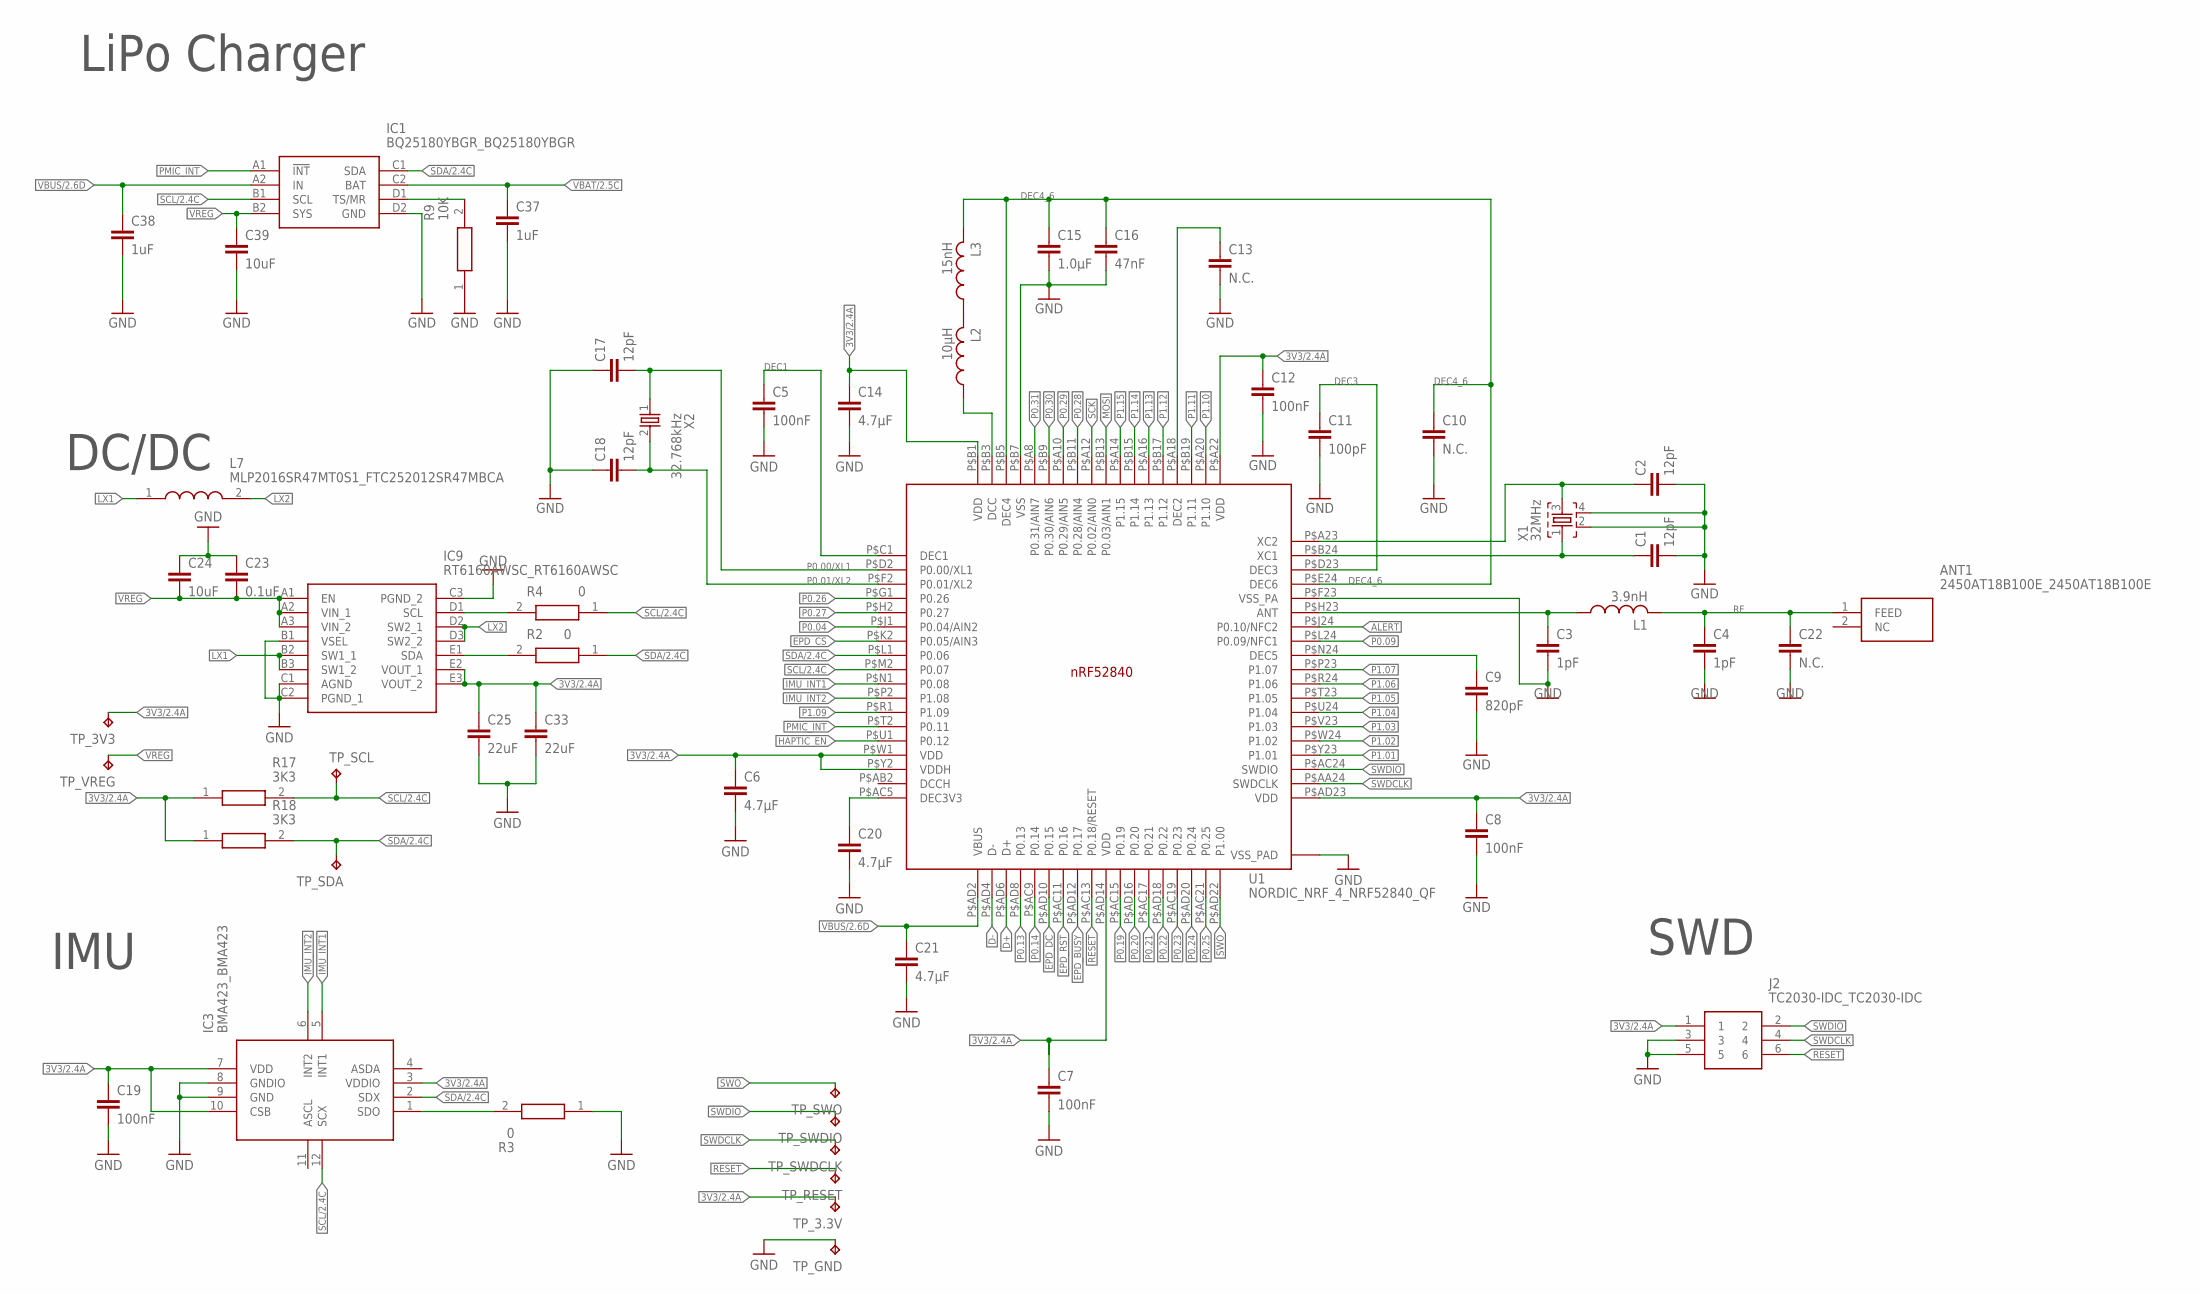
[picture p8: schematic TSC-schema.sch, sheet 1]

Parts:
ANT1: 2450AT18B100E_2450AT18B100E; 2450AT18B100E_ANTC3216X140N
C1, C2, C17, C18: 12pF; NORDIC_NRF_3_RESC0201_L
C3, C4: 1pF; NORDIC_NRF_3_RESC0201_L
C5, C7, C8, C12, C19: 100nF; NORDIC_NRF_3_RESC0201_L
C6, C14, C20, C21: 4.7µF; NORDIC_NRF_3_RESC0201_L
C9: 820pF; NORDIC_NRF_3_RESC0201_L
C10, C13, C22: N.C.; NORDIC_NRF_3_RESC0201_L
C11: 100pF; NORDIC_NRF_3_RESC0201_L
C15: 1.0µF; NORDIC_NRF_3_RESC0201_L
C16: 47nF; NORDIC_NRF_3_RESC0201_L
C23: 0.1uF; NORDIC_NRF_3_RESC0201_L
C24, C39: 10uF; NORDIC_NRF_3_RESC0201_L
C25, C33: 22uF; NORDIC_NRF_3_RESC0201_L
C37, C38: 1uF; NORDIC_NRF_3_RESC0402_L
IC1: BQ25180YBGR_BQ25180YBGR; BQ25180YBGR_BGA8C40P2X4_100X155X50
IC3: BMA423_BMA423
IC9: RT6160AWSC_RT6160AWSC; RT6160AWSC_BGA15C40P3X5_140X230X60
J2: TC2030-IDC_TC2030-IDC; TC2030-IDC_TC2030IDC
L1: 3.9nH; NORDIC_NRF_2_RESC0402_L
L2: 10µH; NORDIC_NRF_2_RESC0402_L
L3: 15nH; NORDIC_NRF_2_RESC0402_L
L7: MLP2016SR47MT0S1_FTC252012SR47MBCA; MLP2016SR47MT0S1_INDC2016X100N
R2, R3, R4: 0; CPF0201D7K68C1_0201
R9: 10K; CPF0201D7K68C1_0201
R17, R18: 3K3; CPF0201D7K68C1_0201
TP_3.3V, TP_3V3: HECTOR_WATCH_1_TPTP20R; HECTOR_WATCH_1_TP20R
TP_GND: HECTOR_WATCH_1_TPTP20R; HECTOR_WATCH_1_TP20R
TP_RESET: HECTOR_WATCH_1_TPTP20R; HECTOR_WATCH_1_TP20R
TP_SCL: HECTOR_WATCH_1_TPTP20R; HECTOR_WATCH_1_TP20R
TP_SDA: HECTOR_WATCH_1_TPTP20R; HECTOR_WATCH_1_TP20R
TP_SWDCLK: HECTOR_WATCH_1_TPTP20R; HECTOR_WATCH_1_TP20R
TP_SWDIO: HECTOR_WATCH_1_TPTP20R; HECTOR_WATCH_1_TP20R
TP_SWO: HECTOR_WATCH_1_TPTP20R; HECTOR_WATCH_1_TP20R
TP_VREG: HECTOR_WATCH_1_TPTP20R; HECTOR_WATCH_1_TP20R
U1: NORDIC_NRF_4_NRF52840_QF; NORDIC_NRF_4_AQFN50P700X700X85_HS-74N
X1: 32MHz; NORDIC_NRF_BT-XTAL_2016_N
X2: 32.768kHz; NORDIC_NRF_1_XTAL_3215_N

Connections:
3V3/2.4A: C6.1, C7.1, C8.1, C12.1, C14.1, C19.1, C25.1, C33.1, IC3.3 (VDDIO), IC3.7 (VDD), IC3.10 (CSB), IC9.E2 (VOUT_1), IC9.E3 (VOUT_2), J2.1, R17.1, R18.1, TP_3.3V.TP, TP_3V3.TP, U1.P$A22 (VDD), U1.P$AD14 (VDD), U1.P$AD23 (VDD), U1.P$B1 (VDD), U1.P$W1 (VDD), U1.P$Y2 (VDDH)
ALERT: U1.P$J24 (P0.10/NFC2); also elsewhere on the board
D+: U1.P$AD6 (D+); also elsewhere on the board
D-: U1.P$AD4 (D-); also elsewhere on the board
DEC1: C5.1, U1.P$C1 (DEC1)
DEC3: C11.1, U1.P$D23 (DEC3)
DEC4_6: C10.1, C15.1, C16.1, L3.2, U1.P$B5 (DEC4), U1.P$E24 (DEC6)
EPD_BUSY: U1.P$AD12 (P0.17); also elsewhere on the board
EPD_CS: U1.P$K2 (P0.05/AIN3); also elsewhere on the board
EPD_DC: U1.P$AD10 (P0.15); also elsewhere on the board
EPD_RST: U1.P$AC11 (P0.16); also elsewhere on the board
GND: C1.2, C2.2, C3.2, C4.2, C5.2, C6.2, C7.2, C8.2, C9.2, C10.2, C11.2, C12.2, C13.2, C14.2, C15.2, C16.2, C17.1, C18.1, C19.2, C20.2, C21.2, C22.2, C23.1, C24.1, C25.2, C33.2, C37.2, C38.2, C39.2, IC1.D2 (GND), IC3.8 (GNDIO), IC3.9 (GND), IC9.B1 (VSEL), IC9.C1 (AGND), IC9.C2 (PGND_1), IC9.C3 (PGND_2), J2.3, J2.5, R3.1, R9.1, TP_GND.TP, U1.P$74 (VSS_PAD), U1.P$75 (VSS_PAD), U1.P$76 (VSS_PAD), U1.P$77 (VSS_PAD), U1.P$78 (VSS_PAD), U1.P$79 (VSS_PAD), U1.P$80 (VSS_PAD), U1.P$81 (VSS_PAD), U1.P$82 (VSS_PAD), U1.P$83 (VSS_PAD), U1.P$84 (VSS_PAD), U1.P$85 (VSS_PAD), U1.P$86 (VSS_PAD), U1.P$87 (VSS_PAD), U1.P$88 (VSS_PAD), U1.P$89 (VSS_PAD), U1.P$90 (VSS_PAD), U1.P$B7 (VSS), U1.P$F23 (VSS_PA), X1.2, X1.4; also elsewhere on the board
HAPTIC_EN: U1.P$U1 (P0.12); also elsewhere on the board
IMU_INT1: IC3.5 (INT1), U1.P$N1 (P0.08)
IMU_INT2: IC3.6 (INT2), U1.P$P2 (P1.08)
LX1: IC9.B2 (SW1_1), IC9.B3 (SW1_2), L7.1
LX2: IC9.D2 (SW2_1), IC9.D3 (SW2_2), L7.2
MOSI: U1.P$B13 (P0.03/AIN1); also elsewhere on the board
unnamed: C20.1, U1.P$AC5 (DEC3V3)
unnamed: L2.1, U1.P$B3 (DCC)
unnamed: L2.2, L3.1
unnamed: C1.1, U1.P$B24 (XC1), X1.1
unnamed: C2.1, U1.P$A23 (XC2), X1.3
unnamed: C9.1, U1.P$N24 (DEC5)
unnamed: C13.1, U1.P$A18 (DEC2)
unnamed: C3.1, L1.1, U1.P$H23 (ANT)
unnamed: IC1.D1 (TS/MR), R9.2
unnamed: IC3.1 (SDO), R3.2
unnamed: IC9.D1 (SCL), R4.2
unnamed: IC9.E1 (SDA), R2.2
P0.00/XL1: C17.2, U1.P$D2 (P0.00/XL1), X2.1
P0.01/XL2: C18.2, U1.P$F2 (P0.01/XL2), X2.2
P0.04: U1.P$J1 (P0.04/AIN2)
P0.09: U1.P$L24 (P0.09/NFC1)
P0.13: U1.P$AD8 (P0.13); also elsewhere on the board
P0.14: U1.P$AC9 (P0.14); also elsewhere on the board
P0.19: U1.P$AC15 (P0.19)
P0.20: U1.P$AD16 (P0.20)
P0.21: U1.P$AC17 (P0.21)
P0.22: U1.P$AD18 (P0.22)
P0.23: U1.P$AC19 (P0.23)
P0.24: U1.P$AD20 (P0.24)
P0.25: U1.P$AC21 (P0.25)
P0.26: U1.P$G1 (P0.26)
P0.27: U1.P$H2 (P0.27)
P0.28: U1.P$B11 (P0.28/AIN4)
P0.29: U1.P$A10 (P0.29/AIN5)
P0.30: U1.P$B9 (P0.30/AIN6)
P0.31: U1.P$A8 (P0.31/AIN7)
P1.01: U1.P$Y23 (P1.01); also elsewhere on the board
P1.02: U1.P$W24 (P1.02); also elsewhere on the board
P1.03: U1.P$V23 (P1.03)
P1.04: U1.P$U24 (P1.04)
P1.05: U1.P$T23 (P1.05)
P1.06: U1.P$R24 (P1.06)
P1.07: U1.P$P23 (P1.07)
P1.09: U1.P$R1 (P1.09)
P1.10: U1.P$A20 (P1.10)
P1.11: U1.P$B19 (P1.11)
P1.12: U1.P$B17 (P1.12)
P1.13: U1.P$A16 (P1.13)
P1.14: U1.P$B15 (P1.14)
P1.15: U1.P$A14 (P1.15)
PMIC_INT: IC1.A1 (!INT), U1.P$T2 (P0.11)
RESET: J2.6, TP_RESET.TP, U1.P$AC13 (P0.18/RESET)
RF: ANT1.1 (FEED), C4.1, C22.1, L1.2
SCK: U1.P$A12 (P0.02/AIN0); also elsewhere on the board
SCL/2.4C: IC1.B1 (SCL), IC3.12 (SCX), R4.1, R17.2, TP_SCL.TP, U1.P$M2 (P0.07)
SDA/2.4C: IC1.C1 (SDA), IC3.2 (SDX), R2.1, R18.2, TP_SDA.TP, U1.P$L1 (P0.06)
SWDCLK: J2.4, TP_SWDCLK.TP, U1.P$AA24 (SWDCLK)
SWDIO: J2.2, TP_SWDIO.TP, U1.P$AC24 (SWDIO)
SWO: TP_SWO.TP, U1.P$AD22 (P1.00)
VBAT/2.5C: C37.1, IC1.C2 (BAT)
VBUS/2.6D: C21.1, C38.1, IC1.A2 (IN), U1.P$AD2 (VBUS)
VREG: C23.2, C24.2, C39.1, IC1.B2 (SYS), IC9.A1 (EN), IC9.A2 (VIN_1), IC9.A3 (VIN_2), TP_VREG.TP

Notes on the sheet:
LiPo Charger
DC/DC
IMU
SWD

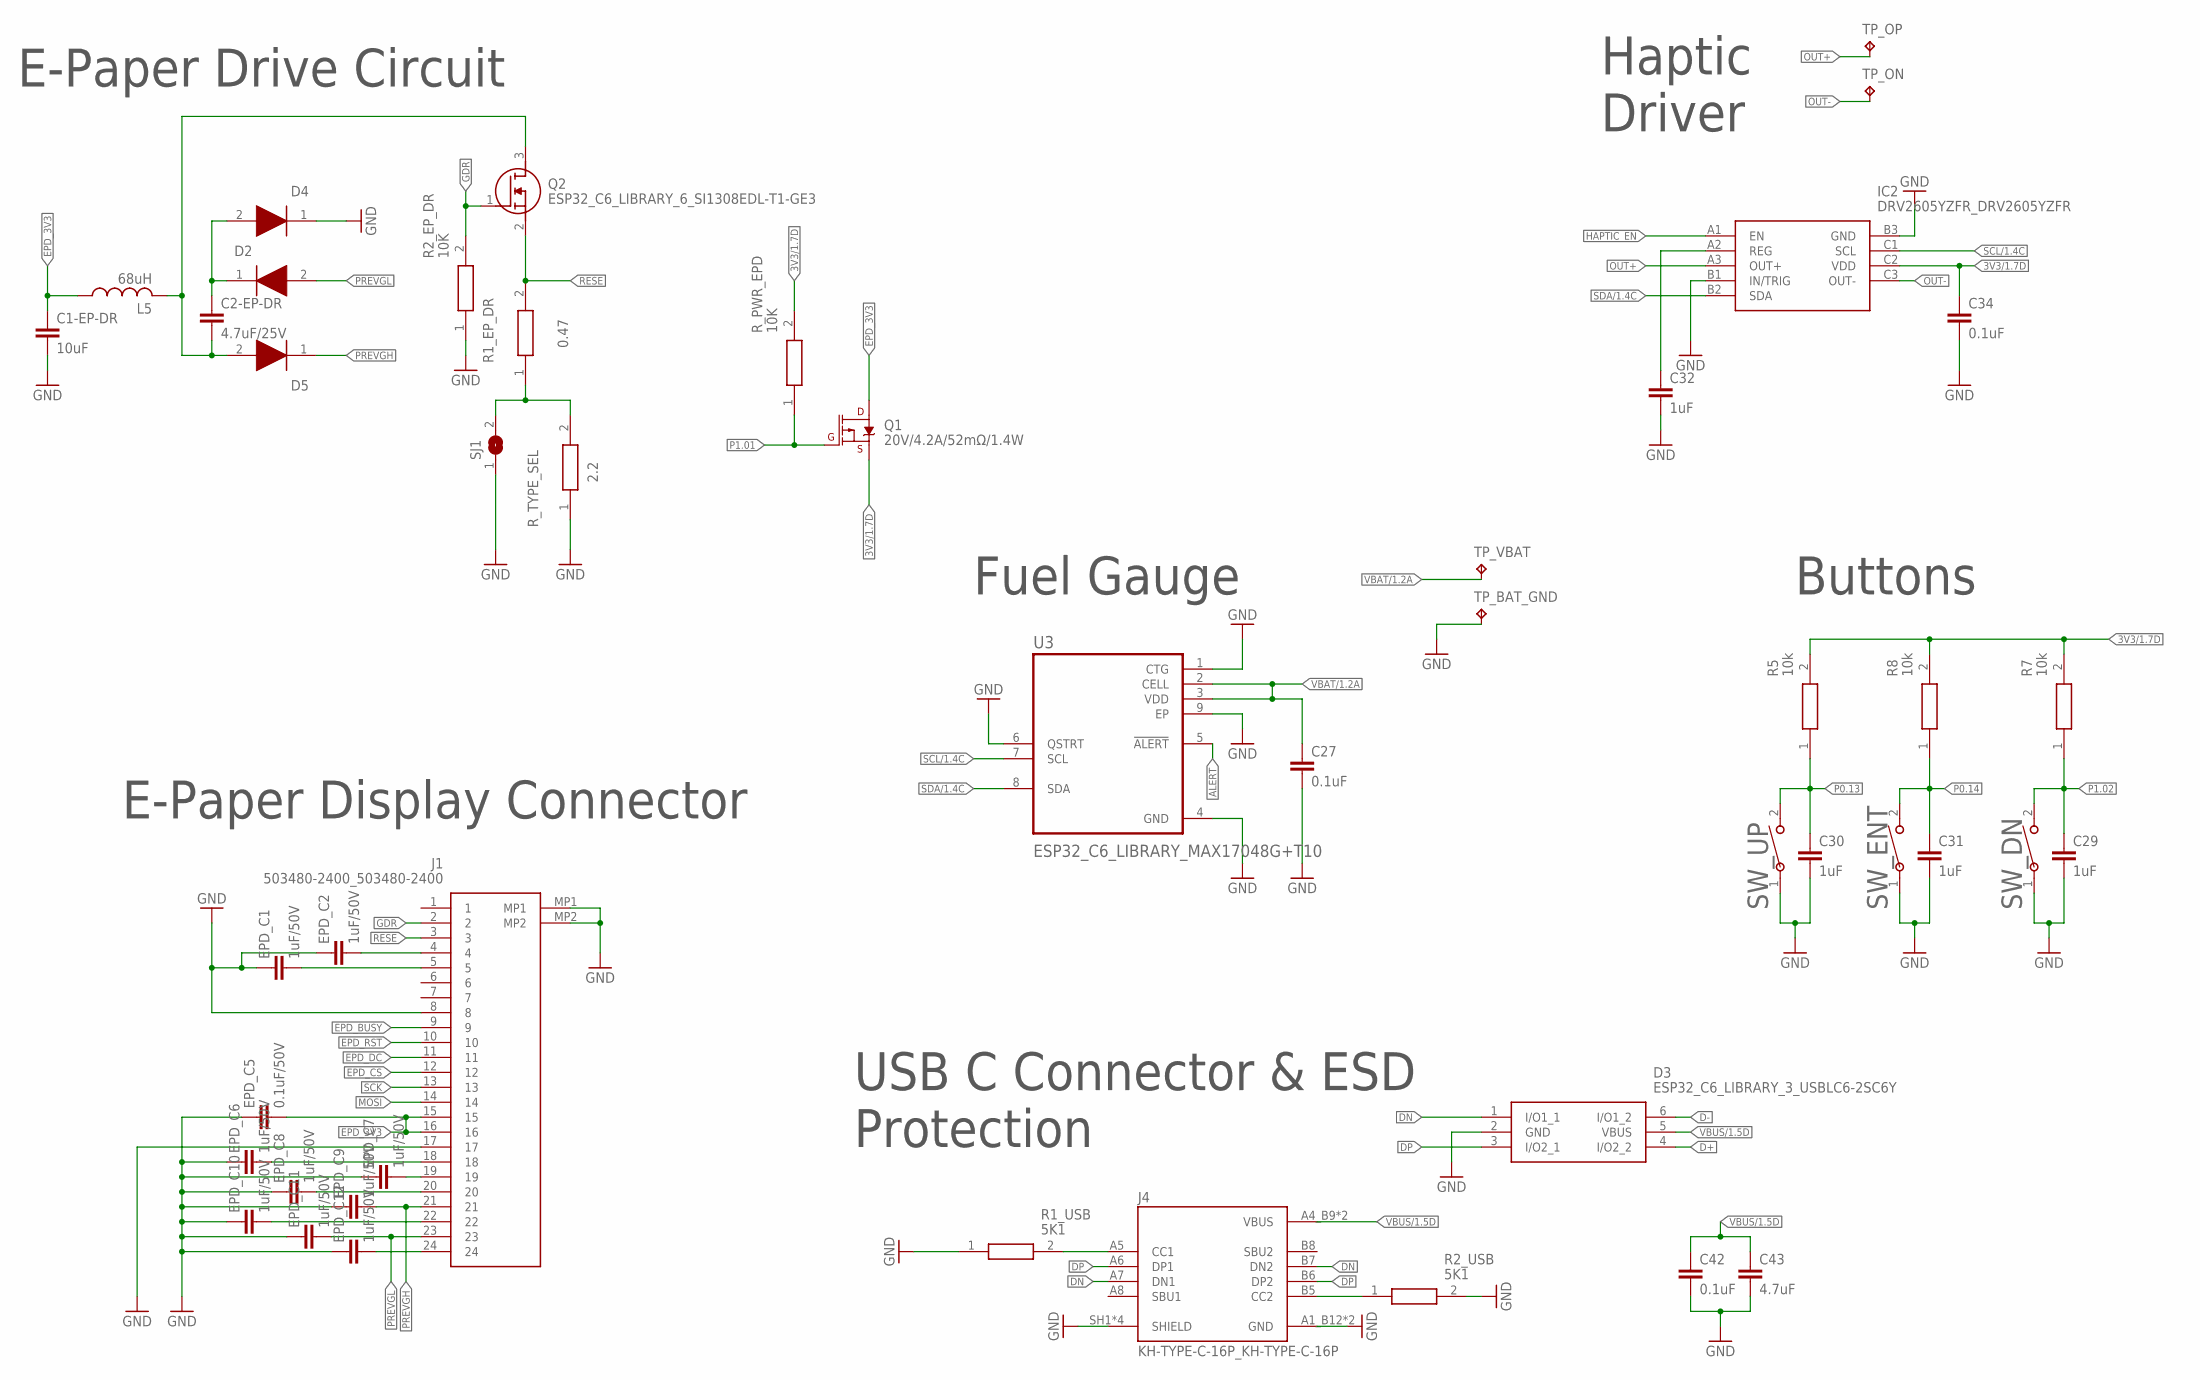
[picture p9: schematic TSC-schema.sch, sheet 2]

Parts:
C1-EP-DR: 10uF; NORDIC_NRF_3_RESC0402_L
C2-EP-DR: 4.7uF/25V; NORDIC_NRF_3_RESC0201_L
C27, C34, C42: 0.1uF; NORDIC_NRF_3_RESC0201_L
C29, C30, C31, C32: 1uF; NORDIC_NRF_3_RESC0402_L
C43: 4.7uF; NORDIC_NRF_3_RESC0201_L
D2, D4, D5: ESP32_C6_LIBRARY_5_MBR0530; ESP32_C6_LIBRARY_5_SOD3716X135N
D3: ESP32_C6_LIBRARY_3_USBLC6-2SC6Y; ESP32_C6_LIBRARY_3_SOT95P280X145-6N
EPD_C1, EPD_C2, EPD_C6, EPD_C7, EPD_C8, EPD_C9, EPD_C10, EPD_C11, EPD_C12: 1uF/50V; NORDIC_NRF_3_RESC0201_L
EPD_C5: 0.1uF/50V; NORDIC_NRF_3_RESC0201_L
IC2: DRV2605YZFR_DRV2605YZFR; DRV2605YZFR_BGA9C50P3X3_144X144X62
J1: 503480-2400_503480-2400; 503480-2400_5034802400
J4: KH-TYPE-C-16P_KH-TYPE-C-16P; KH-TYPE-C-16P_KINGHELM_KH-TYPE-C-16P
L5: 68uH; NORDIC_NRF_2_RESC0402_L
Q1: 20V/4.2A/52mΩ/1.4W; ESP32_C6_LIBRARY_4_ESP32_C6_LIBRARY_4_ESP32_C6_LIBRARY_4_ES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
Q2: ESP32_C6_LIBRARY_6_SI1308EDL-T1-GE3; ESP32_C6_LIBRARY_6_SOT65P210X110-3N
R1_EP_DR: 0.47; CPF0201D7K68C1_0201
R1_USB, R2_USB: 5K1; CPF0201D7K68C1_0201
R2_EP_DR: 10K; CPF0201D7K68C1_0201
R5, R7, R8: 10k; CPF0201D7K68C1_0201
R_PWR_EPD: 10K; CPF0201D7K68C1_0201
R_TYPE_SEL: 2.2; CPF0201D7K68C1_0201
SJ1: ESP32_C6_LIBRARY_7_JUMPER_SJ
SW_DN: 2025-10-22_07-23-44_LIBRARY_EVP-AKE31ASW_EVP-AKE3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; 2025-10-22_07-23-44_LIBRARY_SW_EVP-AKE31A_PAN
SW_ENT: 2025-10-22_07-23-44_LIBRARY_EVP-AKE31ASW_EVP-AKE3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; 2025-10-22_07-23-44_LIBRARY_SW_EVP-AKE31A_PAN
SW_UP: 2025-10-22_07-23-44_LIBRARY_EVP-AKE31ASW_EVP-AKE3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; 2025-10-22_07-23-44_LIBRARY_SW_EVP-AKE31A_PAN
TP_BAT_GND: HECTOR_WATCH_1_TPTP20R; HECTOR_WATCH_1_TP20R
TP_ON: HECTOR_WATCH_1_TPTP20R; HECTOR_WATCH_1_TP20R
TP_OP: HECTOR_WATCH_1_TPTP20R; HECTOR_WATCH_1_TP20R
TP_VBAT: HECTOR_WATCH_1_TPTP20R; HECTOR_WATCH_1_TP20R
U3: ESP32_C6_LIBRARY_MAX17048G+T10; ESP32_C6_LIBRARY_SON50P200X200X80-9N

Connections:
3V3/1.7D: C34.1, IC2.C2 (VDD), Q1.2 (S), R5.2, R7.2, R8.2, R_PWR_EPD.2
ALERT: U3.5 (!ALERT); also elsewhere on the board
D+: D3.4 (I/O2_2); also elsewhere on the board
D-: D3.6 (I/O1_2); also elsewhere on the board
DN: D3.1 (I/O1_1), J4.A7 (DN1), J4.B7 (DN2)
DP: D3.3 (I/O2_1), J4.A6 (DP1), J4.B6 (DP2)
EPD_3V3: C1-EP-DR.1, EPD_C5.2, J1.15, J1.16, L5.1, Q1.3 (D)
EPD_BUSY: J1.9; also elsewhere on the board
EPD_CS: J1.12; also elsewhere on the board
EPD_DC: J1.11; also elsewhere on the board
EPD_RST: J1.10; also elsewhere on the board
GDR: J1.2, Q2.1 (G), R2_EP_DR.2
GND: C1-EP-DR.2, C27.2, C29.2, C30.2, C31.2, C32.2, C34.2, C42.2, C43.2, D3.2 (GND), D4.1 (K), EPD_C1.1, EPD_C2.1, EPD_C5.1, EPD_C6.1, EPD_C7.1, EPD_C8.1, EPD_C9.1, EPD_C10.1, EPD_C11.1, EPD_C12.1, IC2.B1 (IN/TRIG), IC2.B3 (GND), J1.8, J1.17, J1.MP1, J1.MP2, J4.A1_B12 (GND), J4.A12_B1 (GND), J4.SH1 (SHIELD), J4.SH2 (SHIELD), J4.SH3 (SHIELD), J4.SH4 (SHIELD), R1_USB.1, R2_EP_DR.1, R2_USB.2, R_TYPE_SEL.1, SJ1.1, SW_DN.1, SW_ENT.1, SW_UP.1, TP_BAT_GND.TP, U3.1 (CTG), U3.4 (GND), U3.6 (QSTRT), U3.9 (EP); also elsewhere on the board
HAPTIC_EN: IC2.A1 (EN); also elsewhere on the board
MOSI: J1.14; also elsewhere on the board
unnamed: C2-EP-DR.2, D5.2 (A), L5.2, Q2.3 (D)
unnamed: C32.1, IC2.A2 (REG)
unnamed: C2-EP-DR.1, D2.1 (K), D4.2 (A)
unnamed: R1_EP_DR.1, R_TYPE_SEL.2, SJ1.2
unnamed: EPD_C2.2, J1.4
unnamed: EPD_C1.2, J1.5
unnamed: J4.A5 (CC1), R1_USB.2
unnamed: EPD_C6.2, J1.18
unnamed: EPD_C7.2, J1.19
unnamed: EPD_C8.2, J1.20
unnamed: EPD_C10.2, J1.22
unnamed: EPD_C12.2, J1.24
unnamed: J4.B5 (CC2), R2_USB.1
OUT+: IC2.A3 (OUT+), TP_OP.TP
OUT-: IC2.C3 (OUT-), TP_ON.TP
P0.13: C30.1, R5.1, SW_UP.2; also elsewhere on the board
P0.14: C31.1, R8.1, SW_ENT.2; also elsewhere on the board
P1.01: Q1.1 (G), R_PWR_EPD.1; also elsewhere on the board
P1.02: C29.1, R7.1, SW_DN.2; also elsewhere on the board
PREVGH: D5.1 (K), EPD_C9.2, J1.21
PREVGL: D2.2 (A), EPD_C11.2, J1.23
RESE: J1.3, Q2.2 (S), R1_EP_DR.2
SCK: J1.13; also elsewhere on the board
SCL/1.4C: IC2.C1 (SCL), U3.7 (SCL)
SDA/1.4C: IC2.B2 (SDA), U3.8 (SDA)
VBAT/1.2A: C27.1, TP_VBAT.TP, U3.2 (CELL), U3.3 (VDD)
VBUS/1.5D: C42.1, C43.1, D3.5 (VBUS), J4.A4_B9 (VBUS), J4.A9_B4 (VBUS)

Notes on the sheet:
E-Paper Drive Circuit
E-Paper Display Connector
Fuel Gauge
Buttons
Haptic Driver
USB C Connector & ESD Protection

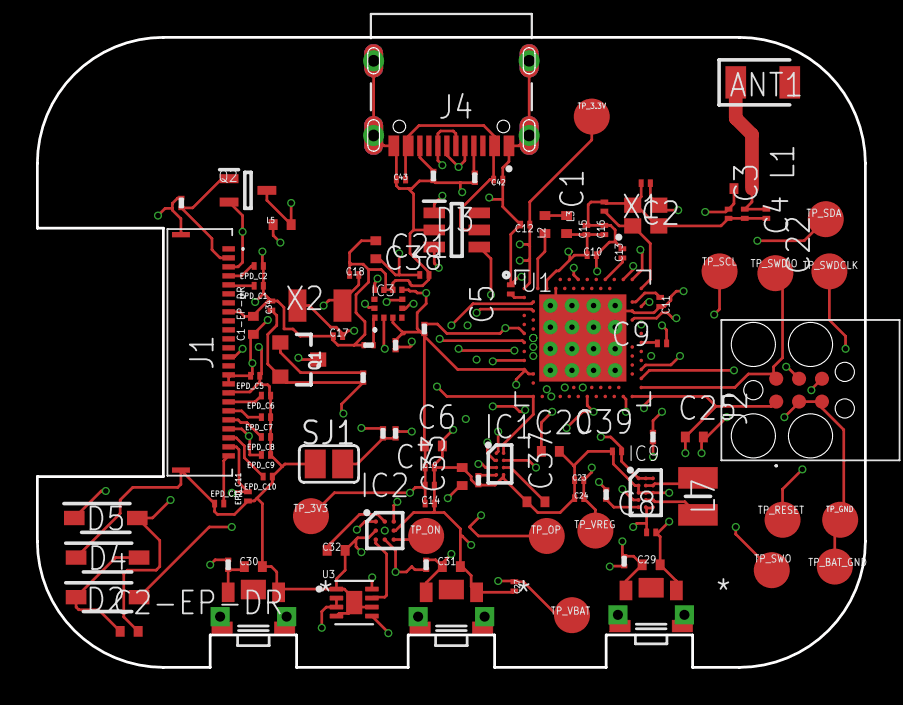
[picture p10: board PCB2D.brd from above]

Board: 4 copper layers, 46.0 x 35.0 mm, 105 parts (0 on the bottom side), 75 nets.

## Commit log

2026-04-21 Add Bill of Materials section to README
    Added Bill of Materials (BOM) section detailing active, critical, and passive components used in the smartwatch project.
2026-04-21 Refactor BOM section for better readability
    Updated the Bill of Materials (BOM) section to improve formatting and clarity.

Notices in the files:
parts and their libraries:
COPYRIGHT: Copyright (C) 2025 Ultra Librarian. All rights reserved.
